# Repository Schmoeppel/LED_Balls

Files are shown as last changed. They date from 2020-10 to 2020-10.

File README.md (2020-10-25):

# LED_Balls
Project for programmable LED-Juggling-Balls with an acc-sensor.  
  
Idea:  
Juggling balls contain an arduino, 3 RGB-LEDs, a Bluetooth-chip and a acc-sensor  
Via an App the Balls can be controlled. Currently those things are possible:  
+choose the balls color  
+set the balls to only light up when they are in the air (acc-sensor is used)  
+run a fixed sequence of lights simultaneously with a song  
  
note: I tried to make the balls recognize the sideswap-pattern they are trown in. But the sensor turned out to be too inaccurate for mentioned task  

Explaination of all files:  
  
Arduino_LED_Ball_Program.ino:  
File which contains the Program that runs the Arduino. It's not very clean yet...  
  
Ball_inner_half/outer_half.stl:  
contain the 3D-Objects to print the juggling Ball. Its two halfes, you can easily take apart and put back together in just a second. For printing use these settings:  
Material: TPU (harder Materials won't work)  
layerheight: 0.1mm  
support: touching bed  
infill: outer_half -> no infill; inner_half -> 10% infill  
  
LED_Ball_Beschl_Sensor_6.apk:  
Code for the phone-app to control up to 6 balls. Created with MIT-Appinventor.  
I am currently learning Flutter to program I nicer and more userfriendly app, which contains more features.  
  
Wiring.fzz:  
Contains the circuit diagram for the hardware components. Created in Fritzing. For easy acces I also included the same diagram as wiring.png  
Components are:  
-Arduino Nano  
-Bluetooth-Chip: HC-05  
-Acc-sensor: MPU6050  
-3x RGB-LEDs with common ground  
-2x 4.7k-pull-up-resistors (normaly the MPU doesn't need them. But for me it sometimes crashed every couple minutes if I wasn't using them)  
-9V Battery  
  
note: probably the esp32 is a better choice as a microcontroller since it has Bluetooth build in, is faster and draws less current. But I didn't know about it until I finished my juggling balls... :(

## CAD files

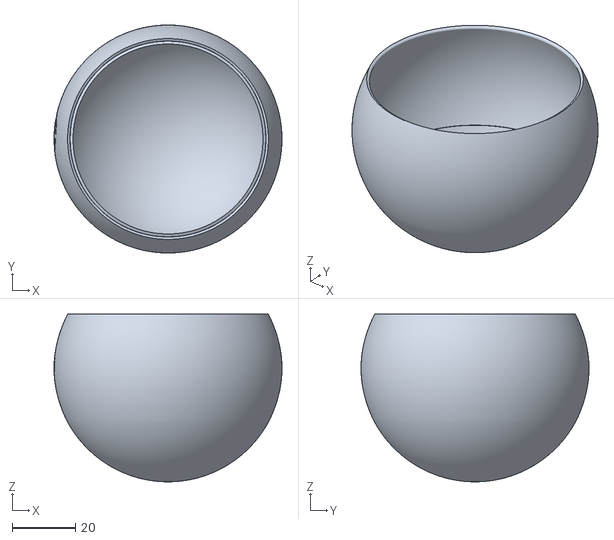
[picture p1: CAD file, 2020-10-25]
Ball_inner_half.stl
72.1 x 72.1 x 53.0

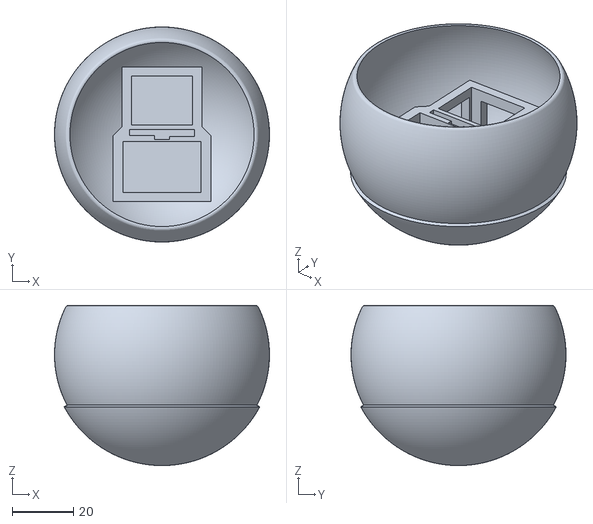
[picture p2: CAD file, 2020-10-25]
Ball_outer_half.stl
70.1 x 70.1 x 52.3

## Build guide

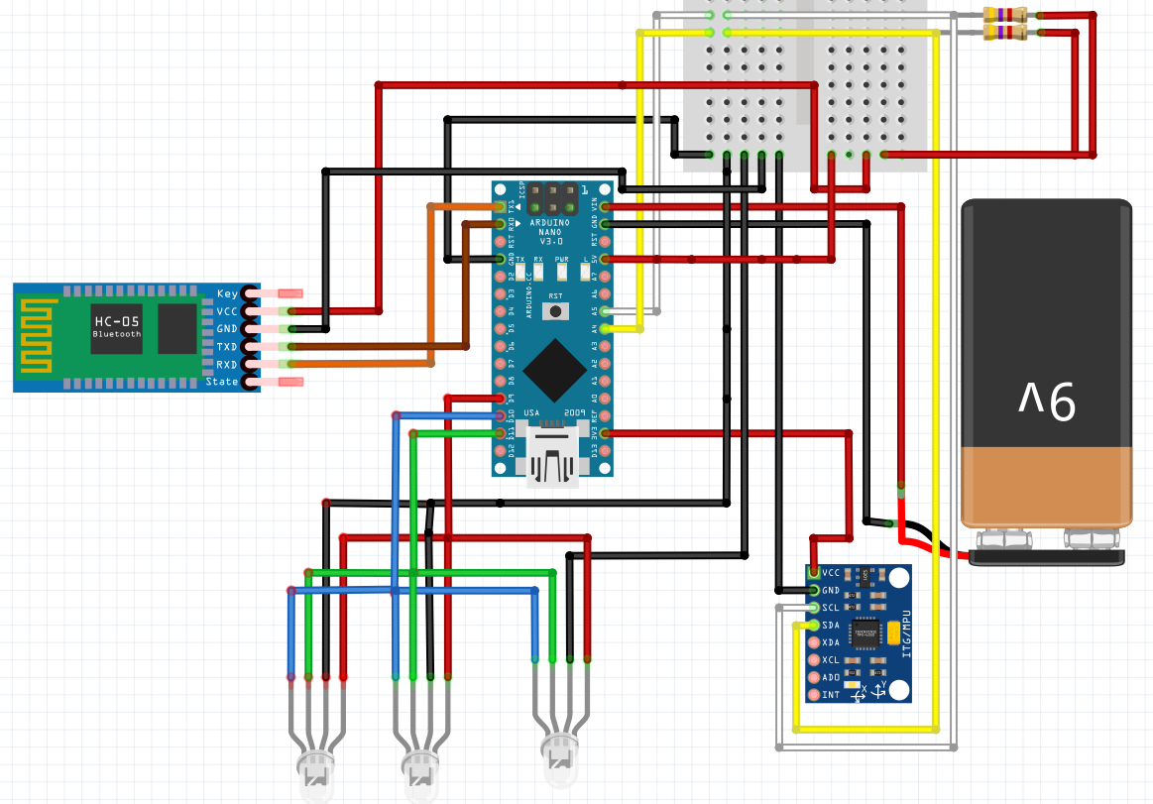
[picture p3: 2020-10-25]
Wiring.png

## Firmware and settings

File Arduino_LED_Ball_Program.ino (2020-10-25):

////#include <FastLED.h>
#include <Wire.h>

////#define NUM_LEDS 24

#define Red_PIN 9
#define Green_PIN 11
#define Blue_PIN 10

short Timing_Korrektur = 150;
short Offset = 300;
uint8_t Testzahl = 1; //vllt nicht mehr gebraucht
uint8_t LED_red;
uint8_t LED_green;
uint8_t LED_blue;
uint8_t red_safe;
uint8_t green_safe;
uint8_t blue_safe;
long millis_song_beginning;

//Variablen zum einlesen von BT-Daten
const byte numChars = 32;
char receivedChars[numChars];
char tempChars[numChars];   // temporary array for use by strtok() function variables to hold the parsed data
boolean newData = false;
int BT_wert;
char BT_signal[numChars] = {0};

//Variablen für SmartSens (Beschleunigungssensor)
bool SD_MenuPressed = false;
bool SD_ColorChange = false;
bool SD_Sideswaps = false;
bool SD_ShowAccel = false;
bool SD_SS_Kalibrierung = false;
long accelX, accelY, accelZ;
float gForceX, gForceY, gForceZ;
uint8_t gForceTotal;
uint8_t cnt;
long gyroX, gyroY, gyroZ;
float rotX, rotY, rotZ;
long millis_ShowAccel;
#define TIMESTEP_SHOWACCEL 150; 

//Beschleunigungssensor Werte Glätten
int GlattFaktor_cnt = 0;
uint8_t gForceGlatt = 0;
uint8_t GlattFaktor = 50; //soviele Werte werden stets zu einer Ausgabe zusammen geführt, und soviele Werte hängt die Ausgabe auch der Realität nach
bool new_gForceGlatt = false;
int gForceGlatt_Summe = 0;

const byte gForceBetragGlatt_samplingrange = 5;
int ThrowThreshold = 1500;
long gForceBetragGlattEinzelWerte[gForceBetragGlatt_samplingrange];
long gForceBetragGlatt_Summe = 0;
int gForceBetrag = 0;

int DataCnt = 0;

uint8_t KorrekturFaktor255 = 255; //muss auch nochmal unten in LED(...) geändert werden, damit Vorzeichen stimmt

//Variablen zur Wurferkennung
/*long Wurfstart_time = 0;
long Wurfende_time = 0;
uint8_t Impulsthreshold = 100; //Wenn dieser Wer überschritten wird, wurde Wurf oder Fangimpuls gemessen. Normaler vom Halten liegt bei 70
bool Impuls_measured = false;
bool WurfCheck = false;
uint8_t Flugphasen_Threshold = 40; //Wenn dieser Wert unterschritten, dann ist Ball in der Luft (sollte dann theoretisch 0 rausgeben)
bool Wurf = true;
long CheckDauer = 0;
long Wurf_Dauer = 0;
*/

//Variablen zur Vereinfachten Erkennung von Color Change
uint8_t ColorChange_FlugPhasen_Threshold = 40;
uint8_t ColorChange_Spin_Threshold = 250;


//Variablen zu vereinfachten Wurferkennung für Sideswaps
long Wurf_Start_Flag = 0;
long Wurf_Ende_Flag = 0;
long Wurf_Dauer_ms = 0;
bool Wurf_Status = true;
float SideSwap_Number_float = 0;
uint8_t SideSwap_Number = 0;
uint8_t SideSwap_FlugPhasen_Threshold = 40; //Unter den Wert müssen die Sensordaten fallen, damit Wurf erkannt wird
bool Wurf_beendet = false;
long Kalibrier_3_Dauer = 300; //Solange läuft eine SideSwap 3. Wert wird über Kalibrierung aktualisiert
//Variablen zum Kalibrieren
uint8_t Kalibriercnt = 0;
long Kalibrierfeedback_timer = 0;
bool Kalibrierfeedback_enable = false;

                 
void setup() { 
  //Initialisiere BT
  Serial.begin(115200);
  
  Serial.println("This demo expects 2 pieces of data - text and an integer");
    Serial.println("Enter data in this style <text,12>  ");
    Serial.println();
    //Serial.write("A123");
    Serial.println("start");

    //Beschleunigungssensor MPU-6050 einrichten
    Wire.begin(); //SCL -> A5;         SDA -> A4
    setupMPU();
    //Serial.println("start");
    
    ////FastLED.addLeds<WS2812B, DATA_PIN, RGB>(leds, NUM_LEDS);
    ////for (int i=0; i<14; i++){
    ////leds[i] = CRGB(2, 200, 2);
    ////}
    ////FastLED.show();
    
    pinMode(Red_PIN, OUTPUT);
    pinMode(Green_PIN, OUTPUT);
    pinMode(Blue_PIN, OUTPUT);
    LED(0,250,0);
    delay(500);
    LED(0, 0, 0);
}

void loop() { 
  //Serial.println("loop1");
  //LED(100, 100, 100);
  BT_Empfangen(); 
  BT_Ausfuehren(); //Befehle ausführen
    //LED(100, 100, 100);
    //Serial.println("loop2");
    SmartDetect();
    //LED(100, 100, 100);
    //Serial.println("loop3");
    
  //Serial.println(gForceBetragGlatt_Summe);
  //Serial.println(gForceTotal);
    
    //nur zum testen der Glättungsfunktion
/*    if (millis_ShowAccel <= millis()){
      if (new_gForceGlatt == true){
        millis_ShowAccel = millis() + TIMESTEP_SHOWACCEL;
        Serial.write('P');
        Serial.write((uint8_t)gForceGlatt);
        new_gForceGlatt = false;
      }
    }*/
    
    /////////////////
    
}

void BT_Empfangen(){
  recvWithStartEndMarkers(); //Empfange Daten
    if (newData == true) { //wenn neue Daten angekommen sind
        strcpy(tempChars, receivedChars);  // this temporary copy is necessary to protect the original data because strtok() replaces the commas with \0
        parseData();  //zerlege Daten, da immer erst ein Buchstabe und dann eine Zahl für unterschiedliche Funktionen kommt
        //BT_Ausfuehren(); //Befehle ausführen
        newData = false; //angekommene Daten wurden abgearbeitet
    }   
}

void BT_Ausfuehren(){
  /////einprogrammierte Lichtfolge starten
    if (BT_signal[0] == 'S'){
      if (BT_wert == 0){
        Song1();
      }
      if (BT_wert == 1){
        Song2();  
      }
      if (BT_wert == 2){
        Synchro();  
      }
      if (BT_wert == 3){
        Song3();  
      }
    }
  /////

  /////beliebiges Signal zurückschicken um bluetoothchannel aufzuwecken
  if (BT_signal[0] == 'Y'){
      if (BT_wert == 0){
        Serial.write('Y');
        Serial.write((uint8_t)0);
      }
    }
  //////

  /////BT Verbindung aufgebaut
  if (BT_signal[0] == 'A'){ 
      LED(0, 255, 0);
      delay(150);
      LED(0, 0, 0);
      delay(150);
      LED(0, 255, 0);
      delay(150);
      LED(0, 0, 0);
      delay(150);
      LED(0, 255, 0);
      delay(150);
      LED(0, 0, 0);
  }
    
  //Follow Challenge////////////////////  
  if (BT_signal[0] == 'F'){
    long FollowChallenge_glowDuration = BT_wert*1000;
    long millis_FollowChallengeEnd = millis()+FollowChallenge_glowDuration; //Ball soll x Sekunden lange rot leuchten
    fading(0, 0, 0, 255, 0, 0, millis(), millis()+4000);
    //LED(255, 0, 0);
    do{ //mache nichts
    }while(millis_FollowChallengeEnd > millis()); // solange nichts machen bis der einprogrammierte Zeitpunkt gekommen ist  
    LED(0, 0, 0); 
  }

  // Ball wieder sichtbar machen
  if (BT_signal[0] == 'E'){
    fading(0, 0, 0, 255, 0, 0, millis(), millis()+3500);
  }
  
  /////Farben manuell über Slider einstellen
  if ((BT_signal[0] =='R') || (BT_signal[0] == 'G') || (BT_signal[0] == 'B')){ 
    if (BT_signal[0] == 'R'){
      LED_red = BT_wert;
      Scrollbars();
    }
    if (BT_signal[0] == 'G'){
      LED_green = BT_wert;
      Scrollbars();
    }
    if (BT_signal[0] == 'B'){
      LED_blue = BT_wert;
      Scrollbars();
    }
  } 
  /////
  
  /////SmartDetect Funktionen Ein-/Aus-stellen
  if (BT_signal[0] == 'M'){
    SD_MenuPressed = true;
  }
  if (BT_signal[0] == 'N'){
    if (BT_wert == 1){
      SD_ColorChange = true;
    }
    else if (BT_wert == 0){
      SD_ColorChange = false;
    }
  }
  if (BT_signal[0] == 'O'){
    if (BT_wert == 1){
      SD_Sideswaps = true;
    }
    else if (BT_wert == 0){
      SD_Sideswaps = false;
    }
  }
  if (BT_signal[0] == 'P'){
    if (BT_wert == 1){
      SD_ShowAccel = true;
    }
    else if (BT_wert == 0){
      SD_ShowAccel = false;
    }
  }
  
  if (BT_signal[0] == 'Q'){ 
    if (BT_wert == 1){
      Kalibrier_3_Dauer = 0; //damit Wert neu berechnet wird
      Kalibriercnt = 0;
      Wurf_beendet = false;
      Wurf_Status = false;
      SD_SS_Kalibrierung = true;
      LED(0, 255, 0);
      delay(150);
      LED(0, 0, 0);
      delay(150);
      LED(0, 255, 0);
      delay(150);
      LED(0, 0, 0);
      delay(150);
      LED(0, 255, 0);
      delay(150);
      LED(0, 0, 0);
    }
  }
  //////////
  BT_signal[0] = 'Z'; //BT_signal auf 'Z' setzen, damit nicht ungewollt nochmal ein Befehl ausgeführt wird (Z nie mit einer Funktion zum Ausführen belegen)
    
}
  
  ////////////Wurfstart und Ende detektieren //Wird nicht gebraucht
/*void Wurfstatus(){
  Impuls_measured = false;
  if (gForceGlatt > Flugphasen_Threshold){
       WurfCheck = false;
     }
  if (((Wurfende_time + 100) < millis()) && (Wurf == false)){ //Wenn das letzte Wurfende erst vor 100ms gemessen werden, wird erstmal alles ignoriert, um überschwingen nicht ausversehen als neuen Wurf zu deuten
     if (gForceGlatt > Impulsthreshold){
       Impuls_measured = true;
       CheckDauer = millis();
       WurfCheck = true;
     }
     if (((CheckDauer + 400) < millis()) &&(WurfCheck == true)){ //Wenn mindestens 400ms lang gecheckt wurde ob beschleunigung unter Flugphasenthreshold lag, dann wird es offiziell zu einem Wurf erklärt
       Wurf = true;
       Wurfstart_time = millis();
     }
  }
  if ((Wurf == true)){
     if (gForceGlatt > Impulsthreshold){ 
       Wurf = false;
       Wurfende_time = millis();
       Wurf_Dauer = Wurfende_time - Wurfstart_time;
     }
  }
}*/
  ///////////////
  
//////Sideswaps erkennen

void SideSwap_Kalibrierung(){
  Kalibrierfeedback_enable = true;  
  
  if ((gForceTotal < SideSwap_FlugPhasen_Threshold) && (Wurf_Status == false)){
    Wurf_Start_Flag = millis();
    Wurf_Status = true;
  }
  else if ((gForceTotal >= SideSwap_FlugPhasen_Threshold) && (Wurf_Status == true)){
    if (Wurf_Status == true){
      Wurf_Status = false;
      Wurf_Ende_Flag = millis();
      Wurf_Dauer_ms = Wurf_Ende_Flag-Wurf_Start_Flag;
      Wurf_beendet = true;
    } 
  }
  if ((Wurf_beendet == true) && (Wurf_Dauer_ms > 300)){ //Testet, dass es wirklich ein Wurf war, und nicht nur ein kurzes Fallen in der Hand etc
    Kalibrier_3_Dauer += Wurf_Dauer_ms;
    Wurf_beendet = false;
    Kalibriercnt++;
    LED(255,0,255); //Kurz den Ball in grün aufleuchten lassen, wenn ein Kalibrierwurf geglückt ist
    Kalibrierfeedback_timer = millis() + 100;
  }
  if (Kalibriercnt >= 3){ //3 Testwürfe um Standardzeit für Wurf zu ermitteln
    Kalibrier_3_Dauer = Kalibrier_3_Dauer/Kalibriercnt; 
    Kalibriercnt = 0;
    Serial.write('Q');
    Serial.write((uint8_t)(Kalibrier_3_Dauer/20)); //durch 20, damit wert als uint8 an Handy geschickt werden kann. Aber eigentlich braucht das Handy den Wert auch nicht. Ist nur für mich als Feedback ob er grob passt 
    SD_SS_Kalibrierung = false;
  }
}

void SideSwap_Detection(){
  if ((gForceTotal < SideSwap_FlugPhasen_Threshold) && (Wurf_Status == false)){
    Wurf_Start_Flag = millis();
    Wurf_Status = true;
  }
  else if ((gForceTotal >= SideSwap_FlugPhasen_Threshold) && (Wurf_Status == true)){
    if (Wurf_Status == true){
      Wurf_Status = false;
      Wurf_Ende_Flag = millis();
      Wurf_Dauer_ms = Wurf_Ende_Flag-Wurf_Start_Flag;
      Wurf_beendet = true;
    } 
  }
  if ((Wurf_beendet == true) && (Wurf_Dauer_ms > 100)){ //Damit keine zu kurzen Würfe gezählt werden
    Wurf_beendet = false;
    SideSwap_Number_float = 3*Wurf_Dauer_ms/Kalibrier_3_Dauer; //Berechnung der Sideswapnummer als float. Die 3, da die Kalibriersauer auf 3en bezogen ist
    SideSwap_Number_float += 0.5; //Damit beim Abschneiden auf uint8_t richtig gerundet wird    
    SideSwap_Number = (uint8_t)(SideSwap_Number_float);
    Serial.write('O');
    Serial.write((uint8_t)SideSwap_Number);
  }  
}

///////////Color Change bei Wurf
void ColorChange_onThrow(int green_Wurf, int red_Wurf, int blue_Wurf, int green_Hand, int red_Hand, int blue_Hand){
  //if ((gForceBetragGlatt_Summe > ThrowThreshold)){
  //if ((gForceTotal < ColorChange_FlugPhasen_Threshold) || (gForceTotal > ColorChange_Spin_Threshold)){
  
  if ((gForceTotal < ColorChange_FlugPhasen_Threshold)){
  //if ((gForceGlatt < ColorChange_FlugPhasen_Threshold) || (gForceGlatt > ColorChange_Spin_Threshold)){  
    LED(green_Wurf, red_Wurf, blue_Wurf); 
  }
  else {
    LED(green_Hand, red_Hand, blue_Hand);
  }
}
//////////////////

void Scrollbars(){
  //LEDs neu ansteuern 
  ////for (int i=0; i<24; i++){ 
  ////  leds[i] = CRGB(LED_green, LED_red, LED_blue); 
  ////}
  ////FastLED.show(); //Signal an LEDs schicken
  LED(LED_red, LED_green, LED_blue); 
}
  
void Synchro(){
    Serial.write('S');  // Zahl an Handy zurückschicken als Zeichen, dass BT angekommen ist, damit Handy berechnen kann wie lange Übertragung gedauert hat
    millis_song_beginning = millis(); //checken wann Lichtfolge angefangen hat um diesen Wert mit den globalen millis() abzugleichen

    while (Serial.available() < 2){//Serial.write("gefangen");
  }; //Warten auf den Korrekturfaktor den das Handy berechnet und zurück schickt
    Timing_Korrektur = Serial.read() << 8;
    Timing_Korrektur += Serial.read();
    
    millis_song_beginning = millis_song_beginning - int(Timing_Korrektur/2) +Offset; //Startzeitpunkt um den Korrekturfaktor verschieben, damit Handy und Bälle synchron sind; Korrektur durch 2, da Signal einmal hin und wieder zurück zum Handy geht

    aufleuchten(0, 100, 0, 0);
    aufleuchten(0, 0, 0, 500);
    aufleuchten(0, 100, 0, 1000);
    aufleuchten(0, 0, 0, 1500);
    
  //wird glaub auch nicht gebraucht
    BT_signal[0] = 'Z'; //BT_signal auf 'Z' setzen, damit nicht ungewollt nochmal ein Befehl ausgeführt wird (Z nie mit einer Funktion zum Ausführen belegen)
    millis_song_beginning = 0;
}

void Song1(){
    Serial.write('S');  // Zahl an Handy zurückschicken als Zeichen, dass BT angekommen ist, damit Handy berechnen kann wie lange Übertragung gedauert hat
    millis_song_beginning = millis(); //checken wann Lichtfolge angefangen hat um diesen Wert mit den globalen millis() abzugleichen

    while (Serial.available() < 2){//Serial.write("gefangen");
  }; //Warten auf den Korrekturfaktor den das Handy berechnet und zurück schickt
    Timing_Korrektur = Serial.read() << 8;
    Timing_Korrektur += Serial.read();
    
    millis_song_beginning = millis_song_beginning - int(Timing_Korrektur/2) +Offset; //Startzeitpunkt um den Korrekturfaktor verschieben, damit Handy und Bälle synchron sind; Korrektur durch 2, da Signal einmal hin und wieder zurück zum Handy geht
    //BT_signal[0] = 'Z'; //BT_signal auf 'Z' setzen, damit nicht ungewollt nochmal ein Befehl ausgeführt wird (Z nie mit einer Funktion zum Ausführen belegen)
    

    //Ball1
    fading(0, 0, 255, 0, 0, 0, 0, 2528);
    fading(0, 0, 0, 0, 0, 255, 2528, 5056);
    fading(0, 0, 255, 0, 0, 0, 5056, 7584);
    fading(0, 0, 0, 0, 0, 255, 7584, 10112);
    fading(0, 0, 255, 0, 0, 0, 10112, 12640);
    fading(0, 0, 0, 0, 0, 255, 12640, 15168);
    fading(0, 0, 255, 0, 0, 0, 15168, 17696);
    fading(0, 0, 0, 0, 0, 255, 17696, 20224);
    fading(0, 0, 255, 0, 0, 0, 20224, 22752);
    fading(0, 0, 0, 0, 0, 255, 22752, 25280);
    fading(0, 0, 255, 0, 0, 0, 25280, 27808);
    fading(0, 0, 0, 0, 0, 255, 27808, 30336);
    fading(0, 0, 255, 0, 0, 0, 30336, 32864);
    fading(0, 0, 0, 0, 0, 255, 32864, 35392);
    fading(0, 0, 255, 0, 0, 0, 35392, 37920);
    fading(0, 0, 0, 0, 0, 255, 37920, 40448);
    fading(0, 0, 255, 0, 0, 0, 40448, 42976);
    fading(0, 0, 0, 0, 0, 255, 42976, 45504);
    fading(0, 0, 255, 0, 0, 0, 45504, 48032);
    fading(0, 0, 0, 0, 0, 255, 48032, 50560);
    fading(0, 0, 255, 0, 0, 0, 50560, 53088);
    fading(0, 0, 0, 0, 0, 255, 53088, 55616);
    fading(0, 0, 255, 0, 0, 0, 55616, 58144);
    fading(0, 0, 0, 0, 0, 255, 58144, 60672);
    fading(0, 0, 255, 0, 0, 0, 60672, 63200);
    fading(0, 0, 0, 0, 0, 255, 63200, 65728);
    fading(0, 0, 255, 0, 0, 0, 65728, 68256);
    fading(0, 0, 0, 0, 0, 255, 68256, 70784);
    fading(0, 0, 255, 0, 0, 0, 70784, 73312);
    fading(0, 0, 0, 0, 0, 255, 73312, 75840);
    fading(0, 0, 255, 0, 0, 0, 75840, 78368);
    fading(0, 0, 0, 0, 0, 255, 78368, 80896);
    fading(0, 0, 255, 0, 0, 0, 80896, 83424);
    fading(0, 0, 0, 0, 0, 255, 83424, 85952);
    fading(0, 0, 255, 0, 0, 0, 85952, 88480);
    fading(0, 0, 0, 0, 0, 255, 88480, 91008);
    fading(0, 0, 255, 0, 0, 0, 91008, 93536);
    fading(0, 0, 0, 0, 0, 255, 93536, 96064);
    fading(0, 0, 255, 0, 0, 0, 96064, 98592);
    fading(0, 0, 0, 0, 0, 255, 98592, 101120);
    fading(0, 0, 255, 0, 0, 0, 101120, 103648);
    fading(0, 0, 0, 0, 0, 255, 103648, 106176);
    fading(0, 0, 255, 0, 0, 0, 106176, 108704);
    fading(0, 0, 0, 0, 0, 255, 108704, 111232);
    fading(0, 0, 255, 0, 0, 0, 111232, 113760);
    fading(0, 0, 0, 0, 0, 255, 113760, 116288);
    fading(0, 0, 255, 0, 0, 0, 116288, 118816);
    fading(0, 0, 0, 0, 0, 255, 118816, 121344);
    fading(0, 0, 255, 0, 0, 0, 121344, 123872);
    fading(0, 0, 0, 0, 0, 255, 123872, 126400);
    fading(0, 0, 255, 255, 255, 255, 126400, 128928);
    fading(255, 255, 255, 0, 0, 0, 131456, 133984);
    fading(0, 0, 0, 255, 255, 255, 133984, 136512);
    fading(255, 255, 255, 0, 0, 0, 136512, 139040);
    fading(0, 0, 0, 255, 255, 255, 139040, 141568);
    fading(255, 255, 255, 0, 0, 0, 141568, 144096);
    fading(0, 0, 0, 255, 255, 255, 144096, 146624);
    fading(255, 255, 255, 0, 0, 0, 146624, 149152);
    fading(0, 0, 0, 255, 255, 255, 149152, 151680);
    fading(255, 255, 255, 0, 0, 0, 151680, 154208);
    fading(0, 0, 0, 255, 255, 255, 154208, 156736);
    fading(255, 255, 255, 0, 0, 0, 156736, 159264);
    fading(0, 0, 0, 255, 255, 255, 159264, 161792);
    fading(255, 255, 255, 0, 0, 0, 161792, 164320);
    fading(0, 0, 0, 255, 255, 255, 164320, 166848);
    fading(255, 255, 255, 0, 0, 0, 166848, 169376);
    fading(0, 0, 0, 255, 255, 255, 169376, 171904);
    fading(255, 255, 255, 0, 0, 0, 171904, 174432);
    fading(0, 0, 0, 255, 255, 255, 174432, 176960);
    fading(255, 255, 255, 0, 0, 0, 176960, 179488);
    fading(0, 0, 0, 255, 255, 255, 179488, 182016);
    fading(255, 255, 255, 0, 0, 0, 182016, 184544);
    fading(0, 0, 0, 255, 255, 255, 184544, 187072);
    fading(255, 255, 255, 0, 0, 0, 187072, 189600);
    fading(0, 0, 0, 255, 255, 255, 189600, 192128);
    fading(255, 255, 255, 0, 0, 0, 197184, 210000);


    /*
    //Leuchtsequenz starten
    aufleuchten(0, 0, 0, 0);
    fading(0, 0, 0, 0, 0, 255, 13000, 15000);
    aufleuchten(0, 0, 0, 20650);
    //aufleuchten(0, 0, 0, 22500);
    //aufleuchten(0, 255, 0, 24500);
    aufleuchten(255, 0, 0, 25400);
    //aufleuchten(0, 0, 0, 26300);
    //aufleuchten(0, 0, 0, 26800);
    aufleuchten(255, 255, 0, 27300);
    aufleuchten(255, 0, 0, 27500);
    aufleuchten(0, 0, 255, 27700);
    aufleuchten(0, 0, 0, 28200);
    fading(0, 0, 0, 255, 255, 255, 27900, 30000);
    fading(255, 255, 255, 0, 0, 0, 30000, 34000);
    */
    
    /*aufleuchten(200, 0, 0, 0);
    aufleuchten(0, 200, 0, 1000);
    aufleuchten(0, 0, 200, 2000);
    aufleuchten(200, 0, 0, 3000);
    aufleuchten(0, 200, 0, 4000);
    aufleuchten(0, 0, 200, 5000);
    aufleuchten(0, 0, 0, 6000);
  */
  
  //ich glaub das hier braucht man nicht
  //  if (Serial.available() > 0){
  //    while (Serial.available() > 0){
  //      Serial.read();  
  //  }
  //  }
  //wird glaub auch nicht gebraucht
    BT_signal[0] = 'Z'; //BT_signal auf 'Z' setzen, damit nicht ungewollt nochmal ein Befehl ausgeführt wird (Z nie mit einer Funktion zum Ausführen belegen)
    millis_song_beginning = 0;
}
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
